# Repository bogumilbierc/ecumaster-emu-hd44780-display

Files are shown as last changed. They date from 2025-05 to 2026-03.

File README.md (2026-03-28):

# Ecumaster EMU Classic HD44780 display #

Simple "dash" for EMU Classic based on Arduino and HD44780 screen.
Connects to EMU serial output on the expansion port.

It is a super inexpensive design, parts in total (without case) should cost less than 50PLN (12 USD).

## Preview ##

Assembled dash
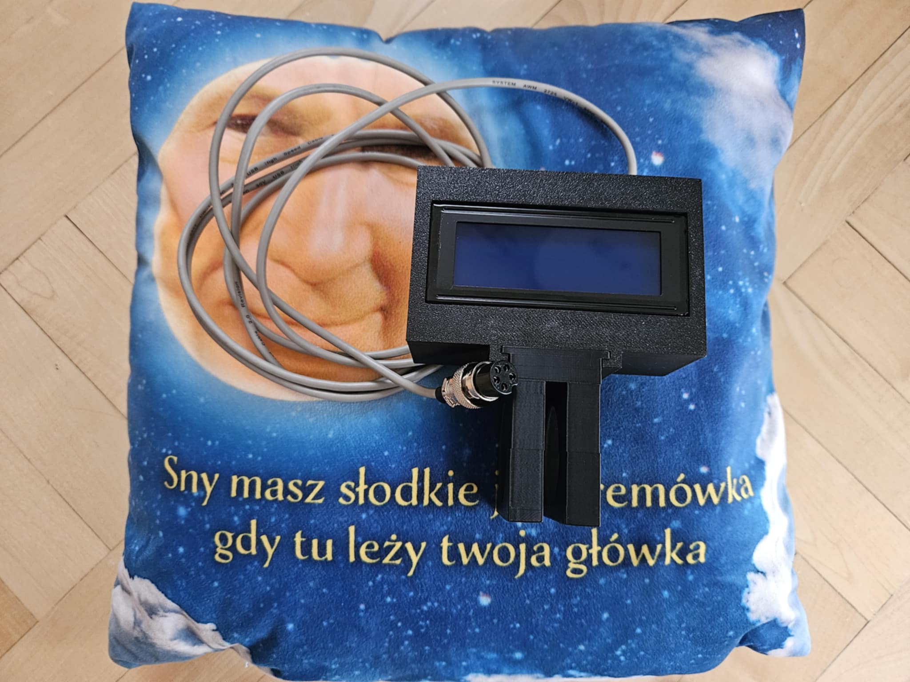
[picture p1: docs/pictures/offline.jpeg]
assembled dash


Dash in a car
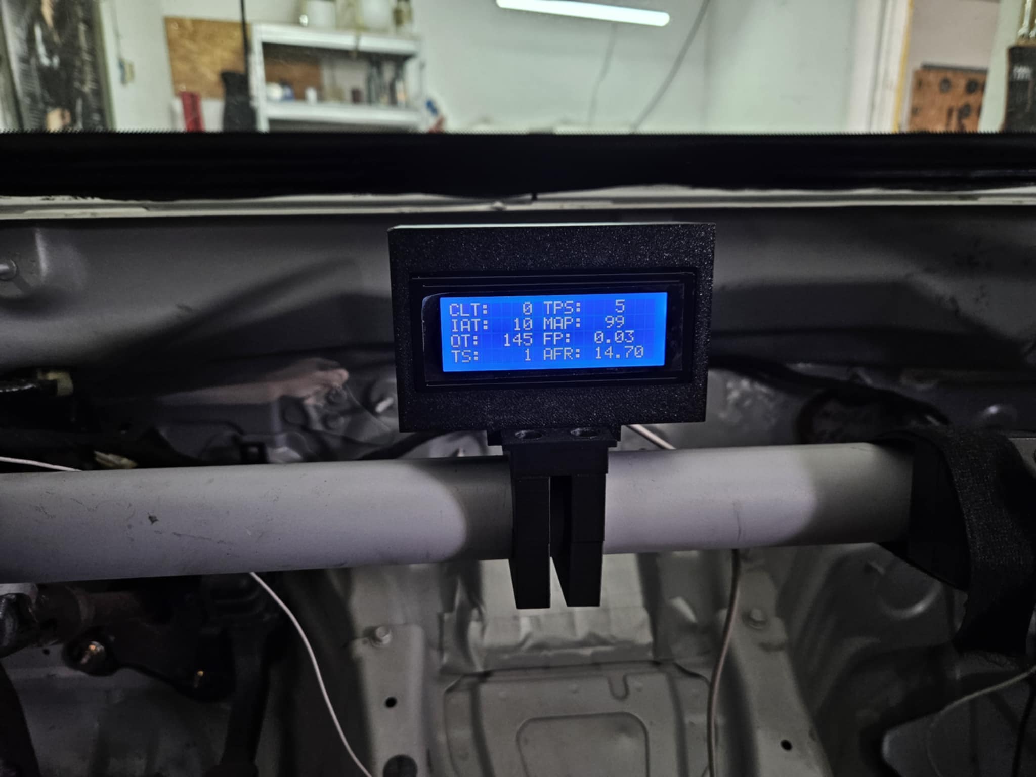
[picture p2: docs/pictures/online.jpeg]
dash in car


## Elements ##

- Arduino Nano

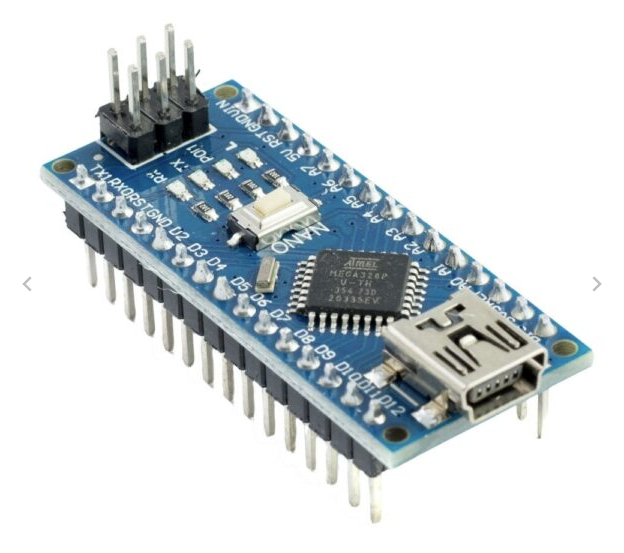
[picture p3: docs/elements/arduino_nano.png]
arduino nano
  
- HD44780 with I2C interface

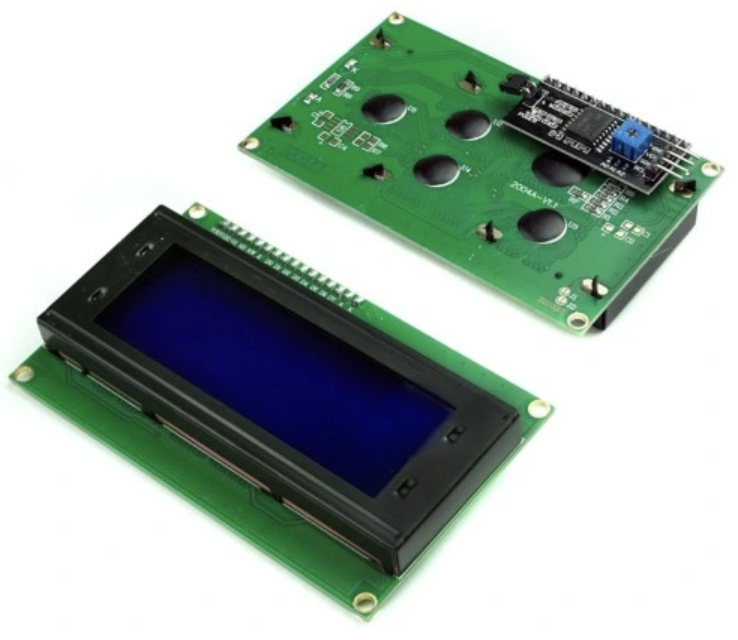
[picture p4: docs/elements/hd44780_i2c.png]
hd44780 i2c
  

- MAX3232 RS232<>TTL converter

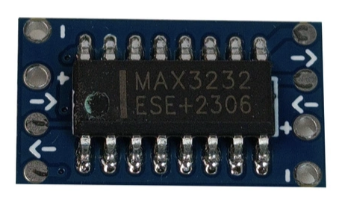
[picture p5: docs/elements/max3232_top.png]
  
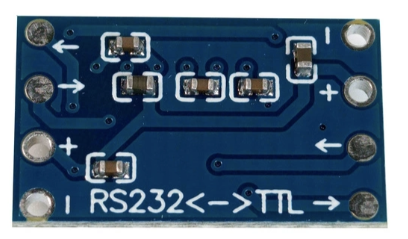
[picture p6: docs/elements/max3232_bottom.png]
  

- GX16 5-pin connector

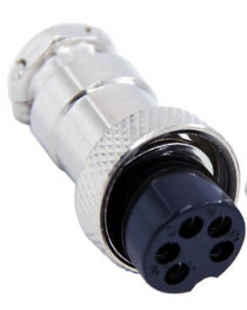
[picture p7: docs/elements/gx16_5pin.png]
gx16 5-pin
  
  
## Dash software versions / projects ##

### dash ###

This versions uses EMU Serial protocol using off the shelf EMUSerial library.

#### Arduino IDE setup #### 
- Install LiquidCrystal_I2C library
- Install EMUSerial library (Note: On Linux You need to modify `~/Arduino/libraries/EMUSerial/src/EMUSerial.h` file and
  replace `#include "arduino.h"` with `#include "Arduino.h"`)

### dash-edl ###

This version uses EMU Serial in EDL-1 mode.

Kudos to https://github.com/ThiloZ/EDLSerial/tree/main for providing library

#### Arduino IDE setup #### 
- Install LiquidCrystal_I2C library
- EDLSerial comes pre-bundled with source code (as it needs to be modified as per use-case)

## Hardware connections ##

### Arduino <> Display ###

| Arduino | Display |
|---|---|
| 5V | VCC |
| GND | GND |
| A4 | SDA |
| A5 | SCL |

### Arduino <> MAX3232 ###

| Arduino | MAX3232 (TTL side) |
|---|---|
| TX | IN |
| RX | OUT |

### EMU <> MAX3232 ###

| EMU | MAX3232 (RS232 side) |
|---|---|
| RXD (pin 1) | OUT |
| TXD (pin 2) | IN |
| +3.3V (pin 3) | unused |
| GND (pin 4) | GND |
| +5V (pin 5) | VCC |

### Wiring diagram ###

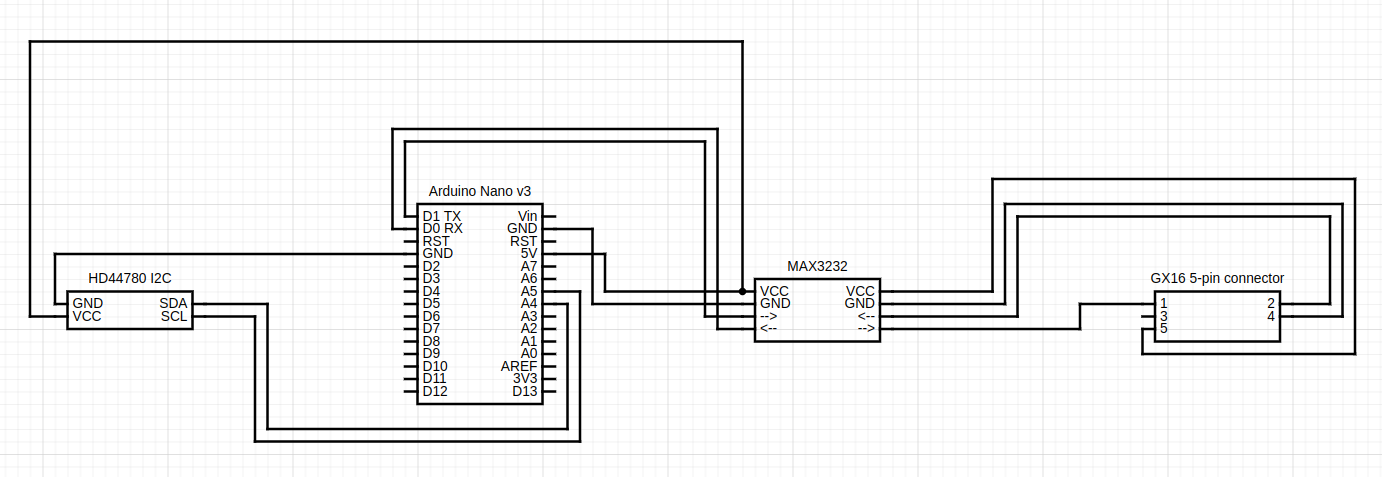
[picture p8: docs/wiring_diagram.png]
wiring diagram


## Flashing assembled board ##

You won't be able to flash a fully assembled board due to the way in which TX and RX pins are wired on Arduino.

Before flashing the board, You need to disconnect TX and RX pins from the board.

## Case ##

Case is a FreeCad project that can be 3D printed. 

It is designed to fit around a 40 mm roll-cage tube, but this can be easily modified in FreeCad.

### Preview ###

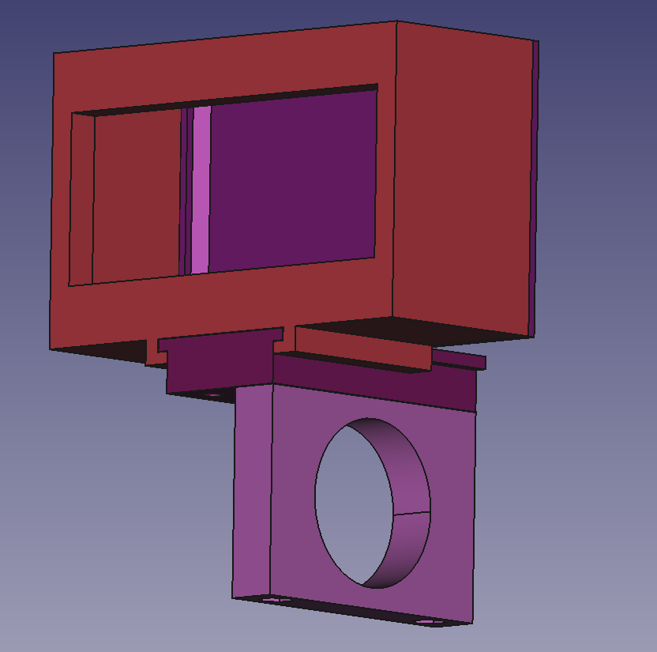
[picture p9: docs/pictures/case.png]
case preview


### Required hardware ###

- 4 M4x50 bolts
- 4 M4 nuts

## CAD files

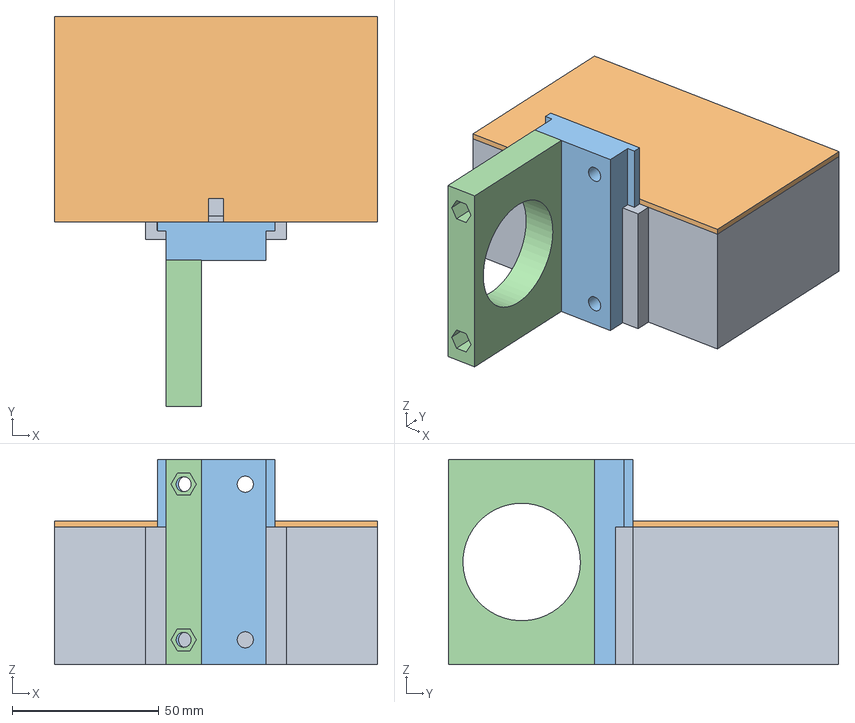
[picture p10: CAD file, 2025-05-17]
case/hd44780_dash_case.FCStd
110.0 x 133.0 x 70.0 mm
MainCaseBody
RearCaseLidBody
RollcageMountAdapterBody
Rollcage40mmMountBody

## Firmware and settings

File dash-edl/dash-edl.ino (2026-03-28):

#include <Wire.h>
#include <LiquidCrystal_I2C.h>
#include "EDLSerial.h"
#include <SoftwareSerial.h>

LiquidCrystal_I2C lcd(0x27, 20, 4);
EDLSerial edl;

char intStringBuff[3];

void setup() {
  Serial.begin(115200);
  edl.begin(Serial);

  lcd.init();
  lcd.backlight();
  lcd.clear();
  printSplashScreen();
}

void printSplashScreen() {
  lcd.home();
  lcd.print("DUCK");
  delay(500);
  lcd.setCursor(0, 1);  //jump to new line
  lcd.print("   QUACK");
  delay(500);
  lcd.setCursor(0, 2);  //jump to new line
  lcd.print("      QUACK");
  delay(500);
  lcd.setCursor(0, 3);  //jump to new line
  lcd.print("         QUACK");
  delay(1000);
}

void loop() {

  if (edl.update()) {  //updates the frame, returns true if frame is valid
    printFirstLine();
    printSecondLine();
    printThirdLine();
    printFourthLine();
  }
}

void printFirstLine() {
  lcd.home();

  lcd.print("CLT: ");
  printThreeDigitInt(edl.getFrame().CLT);

  lcd.print(" ");

  lcd.print("WCT: ");
  printThreeDigitInt(edl.getFrame().acEvap);
}

void printSecondLine() {
  lcd.setCursor(0, 1);  //jump to new line

  lcd.print("IAT: ");
  printThreeDigitInt(edl.getFrame().IAT);

  lcd.print(" ");

  lcd.print("MAP: ");
  printThreeDigitInt(edl.getFrame().MAP);
}

void printThirdLine() {
  lcd.setCursor(0, 2);  //jump to new line

  lcd.print("OP: ");
  lcd.print(edl.getFrame().oilPressure);

  lcd.print(" ");

  lcd.print("FP:  ");
  lcd.print(edl.getFrame().fuelPressure);
}

void printFourthLine() {
  lcd.setCursor(0, 3);  //jump to new line

  lcd.print("TS:  ");
  printThreeDigitInt(edl.getFrame().boostTableSet);

  lcd.print(" ");

  lcd.print("AFR: ");
  lcd.print(edl.getFrame().wboLambda);
}

void printThreeDigitInt(int value) {
  sprintf(intStringBuff, "%3d", value);
  lcd.print(intStringBuff);
}

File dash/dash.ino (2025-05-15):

#include <Wire.h>
#include <LiquidCrystal_I2C.h>
#include <EMUSerial.h>
#include <SoftwareSerial.h>

LiquidCrystal_I2C lcd(0x27, 20, 4);
EMUSerial emu(Serial);

char intStringBuff[3];

void setup() {
  Serial.begin(19200);

  lcd.init();
  lcd.backlight();
  lcd.clear();
  printSplashScreen();
}

void printSplashScreen(){
  lcd.home();
  lcd.print("DUCK");
  delay(1500);
  lcd.setCursor(0, 1);  //jump to new line
  lcd.print("   QUACK");
  delay(1500);
  lcd.setCursor(0, 2);  //jump to new line
  lcd.print("      QUACK");
  delay(1500);
  lcd.setCursor(0, 3);  //jump to new line
  lcd.print("         QUACK");
  delay(1500);
  delay(1500);
}

void loop() {
  emu.checkEmuSerial();

  // Available channels: https://github.com/GTO2013/EMUSerial
  printFirstLine();
  printSecondLine();
  printThirdLine();
  printFourthLine();
}

void printFirstLine() {
  lcd.home();

  lcd.print("CLT: ");
  printThreeDigitInt(emu.emu_data.CLT);

  lcd.print(" ");

  lcd.print("TPS: ");
  printThreeDigitInt(emu.emu_data.TPS);
}

void printSecondLine() {
  lcd.setCursor(0, 1);  //jump to new line

  lcd.print("IAT: ");
  printThreeDigitInt(emu.emu_data.IAT);

  lcd.print(" ");

  lcd.print("MAP: ");
  printThreeDigitInt(emu.emu_data.MAP);
}

void printThirdLine() {
  lcd.setCursor(0, 2);  //jump to new line

  lcd.print("OT:  ");
  printThreeDigitInt(emu.emu_data.oilTemperature);

  lcd.print(" ");

  lcd.print("FP:  ");
  lcd.print(emu.emu_data.fuelPressure);
}

void printFourthLine() {
  lcd.setCursor(0, 3);  //jump to new line

  lcd.print("TS:  ");
  printThreeDigitInt(emu.emu_data.tablesSet);

  lcd.print(" ");

  lcd.print("AFR: ");
  lcd.print(emu.emu_data.wboAFR);
}

void printThreeDigitInt(int value) {
  sprintf(intStringBuff, "%3d", value);
  lcd.print(intStringBuff);
}

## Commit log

2025-05-06 Add basic mounting bracket to mount display case to rollcage
    [mounting_bracket_40mm_tube.FCStd]
2025-05-09 Add wiring information and diagram
2025-05-09 Format int values into 3 places to avoid funky screen behaviour
    [dash.ino]
2025-05-15 Add case for 2004 display
    [hd44780_dash_case.FCStd]
2025-05-15 Add rear lid to the case
    [hd44780_dash_case.FCStd]
2025-05-15 Finish case with mounts to 40mm rollcage
    [hd44780_dash_case.FCStd, mounting_bracket_40mm_tube.FCStd]
2025-05-16 Add recess for M5 nut into rollcage mount
    [hd44780_dash_case.FCStd]
2025-05-16 Make rollcage mounts wider; Make recess for nut 8mm
    [hd44780_dash_case.FCStd]
2025-05-17 Make recess for bolt 7.5mm width to cater for m4 bolt; update readme
    [hd44780_dash_case.FCStd]
